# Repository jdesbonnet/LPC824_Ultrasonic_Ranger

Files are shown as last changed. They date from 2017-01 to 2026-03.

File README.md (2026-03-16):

# LPC824_Ultrasonic_Ranger

This is a sonar sensor comprising a LPC824 ARM Cortex M0+ MCU, low cost 40kHz ultrasonic transducers and opamps. The firmware
uses the LPC824 ADC DMA (direct memory access) capability to read analog samples at high speed into SRAM.

Unlike many ranging sensors that output just distance to target, this project is 
designed to capture the entire echo of an ultrasonic 'ping'. Potential uses include
measuring agricultural crop yield. 

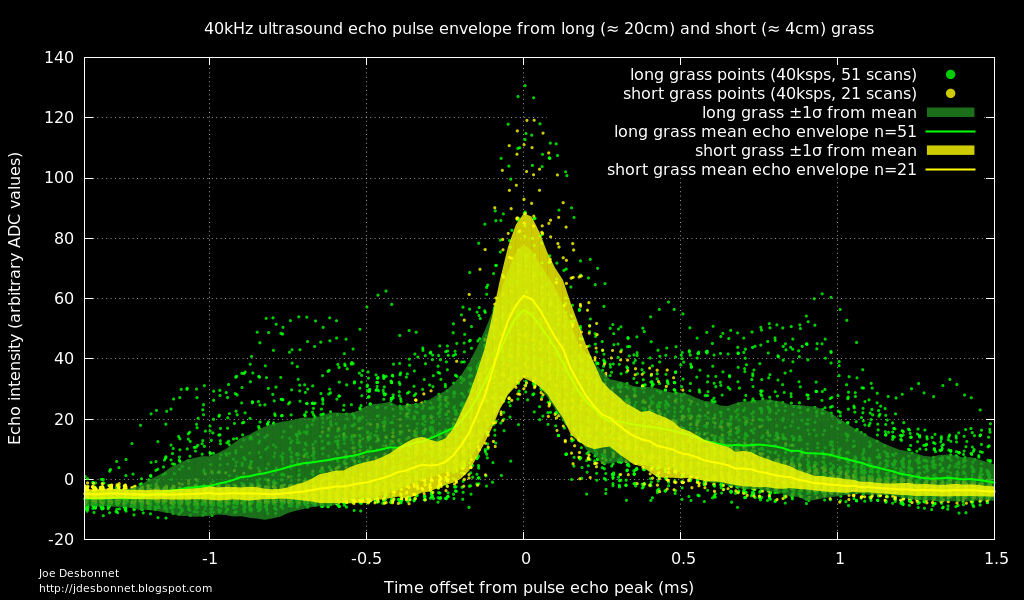
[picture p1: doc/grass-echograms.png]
echograms from long and short grass


## Frequency response of low cost 40kHz transducer

Method: a transmitter and transducer are taped together (separation distance 0).
An oscilloscope (Keysight DSO-X 3014A) waveform generator is set to 5V peak-to-peak 
sine wave, and the receiver is connected to a channel on oscilloscope set to 2V 
per division.  The frequency is varied around 40kHz using waveform generator menu. 
Only one device pair was tested. 

Observation: useful bandwidth is only 1kHz centered at about 40.5kHz. 

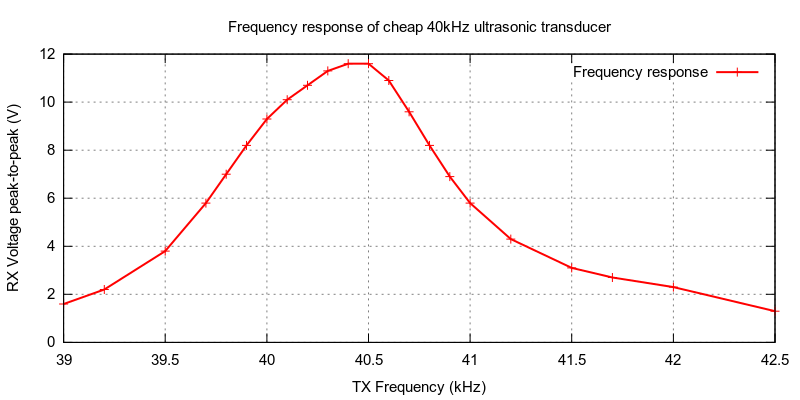
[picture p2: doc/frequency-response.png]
frequency response curve


Pulse (yellow) and echo (green) on oscilloscope:

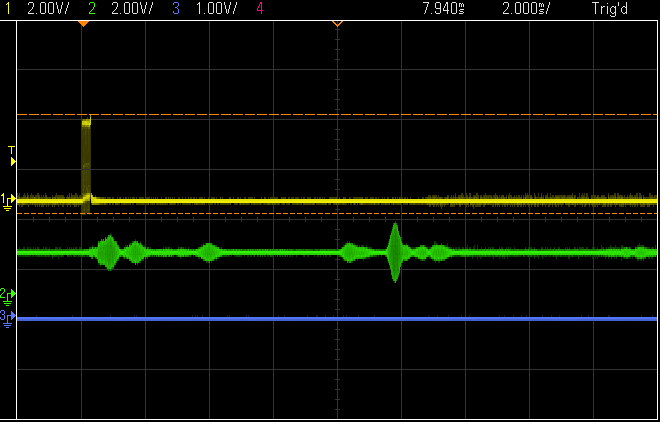
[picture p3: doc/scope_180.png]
echogram


## LPC824 pin utilization

|Pin| Function| |Pin | Function | |
|---| ---| ---|--- |---|---|
| 1 | ADC3 | RX amp out | 20 | PIO_0_14 | Debug pin |
| 2 | ADC9 | 2nd stage RX amp out | 19 | PIO0_0 | UART RXD |
| 3 | PIO0_13 | nc | 18 | VrefP | tied to 3.3V |
| 4 | PIO0_12 | nc | 17 | VrefN | tied to GND |
| 5 | RESET | SWD reset | 16 | Vss | |
| 6 | PIO0_4  | UART TXD | 15 | Vdd | |
| 7 | SWCLK | SWD clock | 14 | PIO0_8 | nc |
| 8 | SWDIO | SWD data | 13 | PIO0_9 | Transducer TX_B |
| 9 | PIO0_11 | nc | 12 | PIO0_1 | nc |
|10 | PIO0_10 | nc | 11 | PIO0_15  | Transducer TX_A |

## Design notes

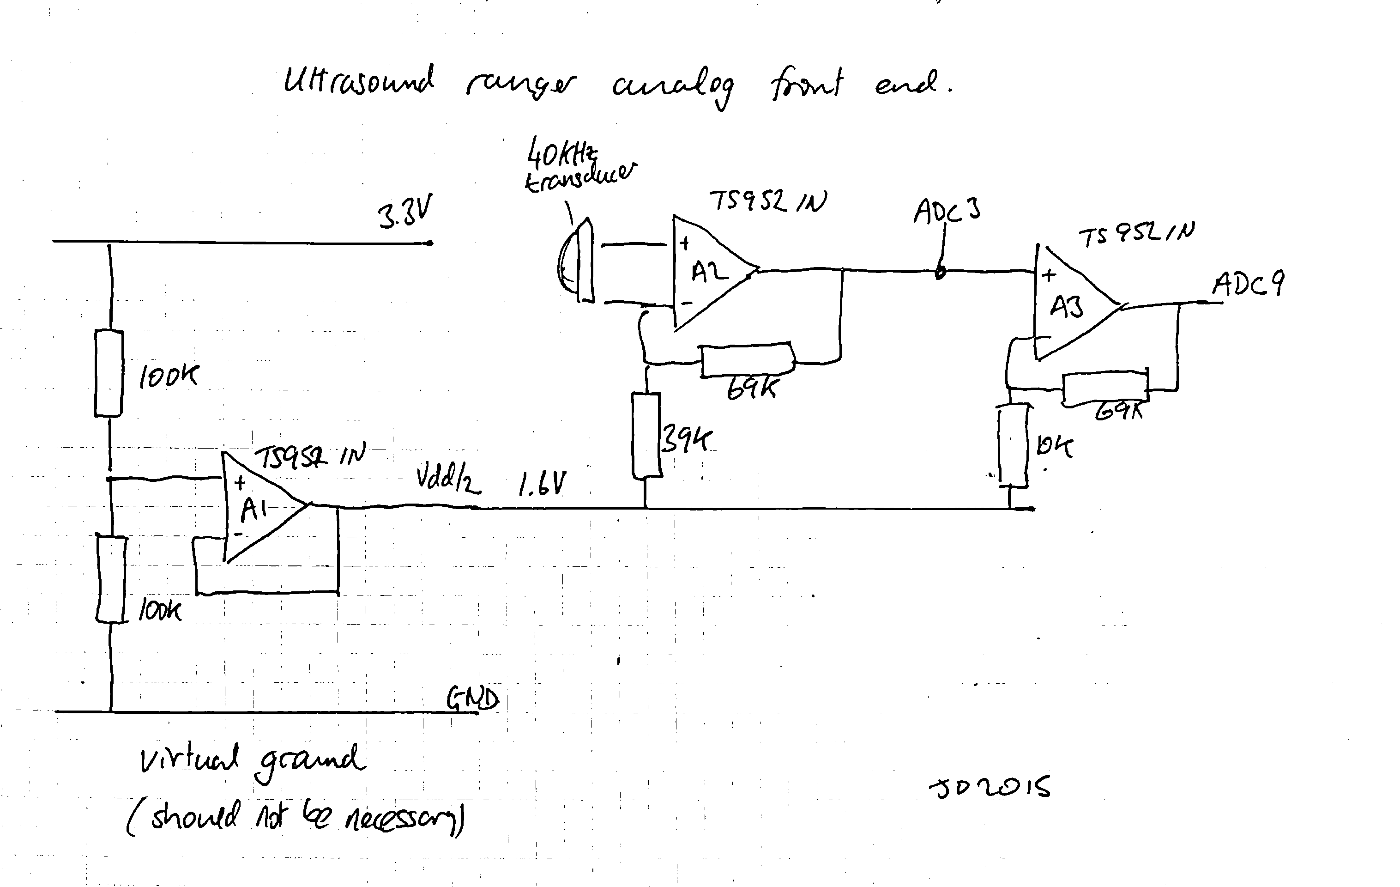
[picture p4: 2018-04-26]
doc/prototype-schematic.png

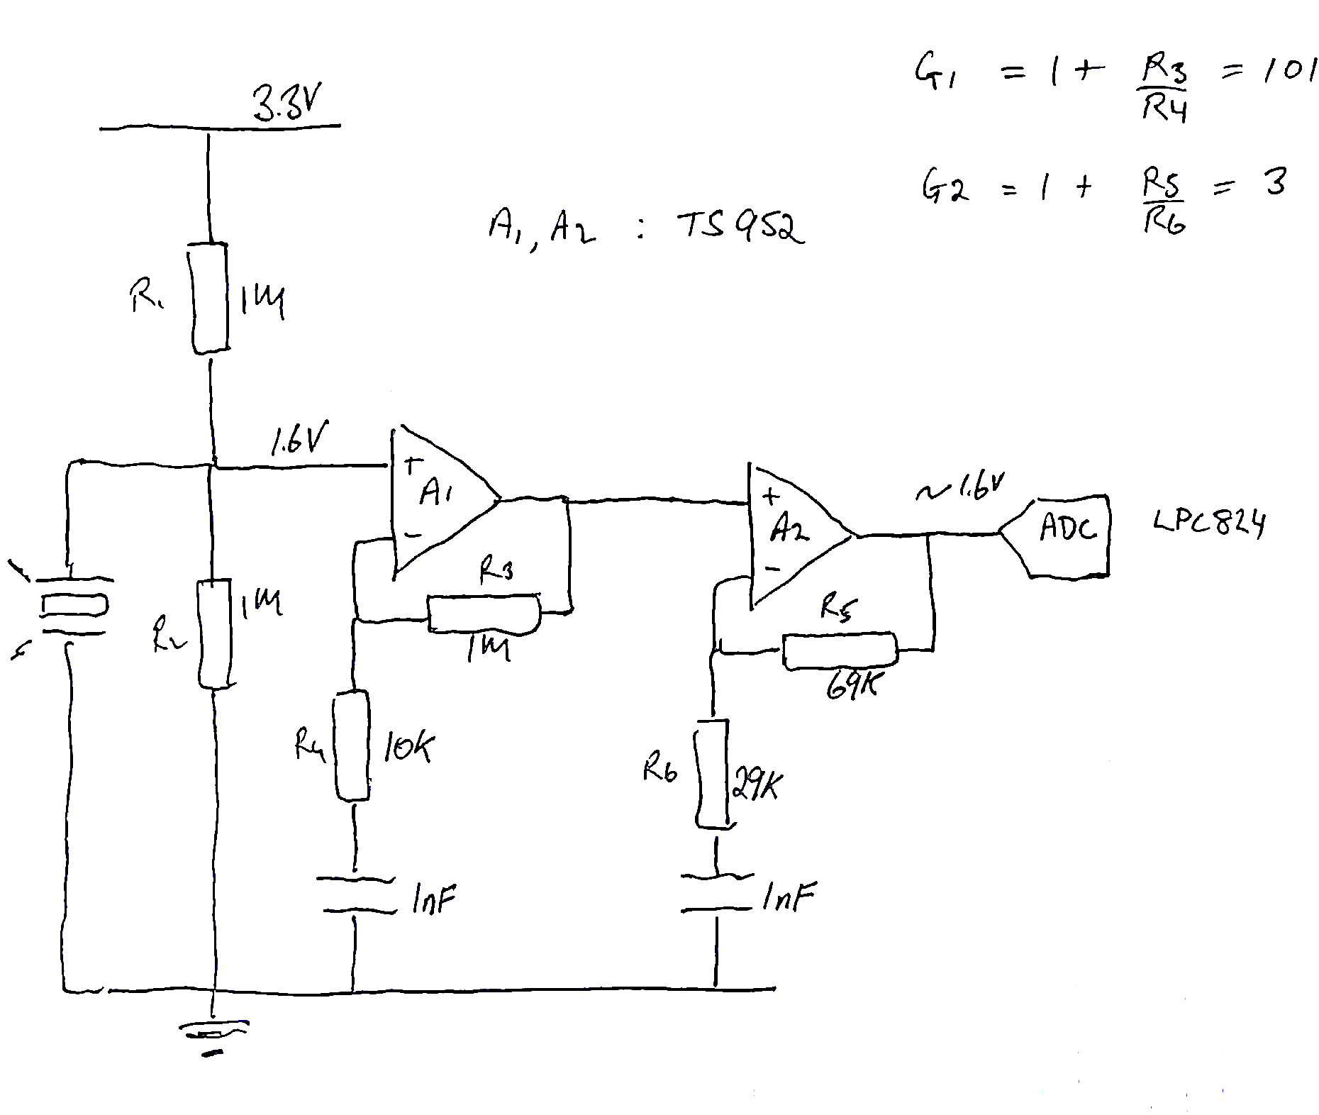
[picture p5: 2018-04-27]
doc/prototype-schematic2.png

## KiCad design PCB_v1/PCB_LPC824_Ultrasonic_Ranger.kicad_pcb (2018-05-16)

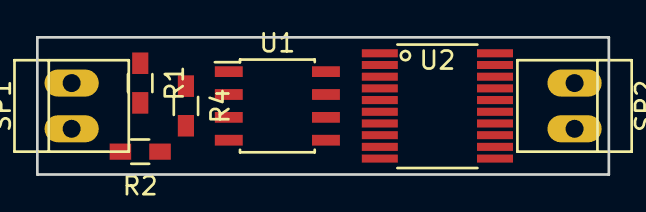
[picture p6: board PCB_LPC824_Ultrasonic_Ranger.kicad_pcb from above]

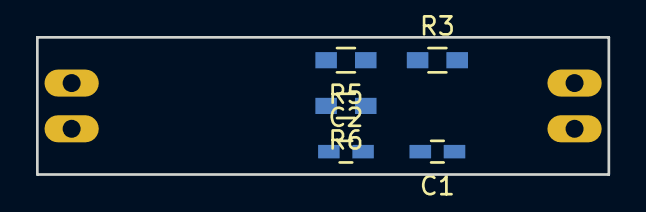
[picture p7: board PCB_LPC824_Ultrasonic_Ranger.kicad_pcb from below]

Board: 2 copper layers, 31.8 x 7.6 mm, 12 parts (5 on the bottom side), 11 nets, no tracks yet.

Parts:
C1, C2: C; C_0603_HandSoldering
R1, R2, R3, R4, R5, R6: R; R_0603_HandSoldering
SP1, SP2: SPEAKER; PINHEAD1-2
U1: OP275; SOIC-8_3.9x4.9mm_Pitch1.27mm
U2: LPC824M201JDH20; TSSOP-20_4.4x6.5mm_Pitch0.65mm

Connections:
+3V3: R1.1, U1.8, U2.15, U2.18
ADC3: R3.1, U1.1, U1.5, U2.1
ADC9: R5.1, U1.7, U2.2
GND: C1.2, C2.2, R2.2, SP1.1, U1.4, U2.16, U2.17
unnamed: C1.1, R4.2
unnamed: C2.1, R6.2
unnamed: R1.2, R2.1, SP1.2, U1.3
unnamed: R3.2, R4.1, U1.2
unnamed: R5.2, R6.1, U1.6
TX_A: SP2.2, U2.10
TX_B: SP2.1, U2.9

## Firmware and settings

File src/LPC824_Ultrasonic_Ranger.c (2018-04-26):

/*
===============================================================================
 Name        : LPC824_Ultrasonic_Ranger.c
 Author      : Joe Desbonnet, jdesbonnet@gmail.com
 Version     : 1.0 (16 July 2015)
 Copyright   : None.
 Description : Ultrasonic ranger application. Use SCT to send 40kHz pulse train
 to TX transducer. RX trandsucer amplified and connected to ADC. Use ADC to SRAM
 DMA to transfer ADC samples directly to memory.

 DMA transfers are limited to 1024 words (which can be 8,16 or 32 bit words). However
 transfers can be chained to facilitate longer data capture. This is illustrated in
 this example by chaining 3 DMA transfers of 1024 words (samples) back-to-back. ADC
 samples are triggered using the SCT (SCT0_OUT3 is programmed as the ADC sample trigger).
 Since the DMA supports transfers of 8, 16, 32 bit words, I am transferring the lower
 16 bits of the ADC data register. Note that bits 15:4 of the ADC data register hold
 the ADC value. So a shift right of 4 bits (>>4) needs to be performed on each
 16 bit word by the CPU after capture to yield ADC values 0 - 4095.

 This example is built upon examples provided by NXP for the LPC824. I recommend having
 chapters 21 (ADC), 11,12 (DMA), 16 (SCT) of UM10800 LPC82x User Manual for reference.

 There is a dependency on the lpc_chip_82x project/library which can be downloaded from:
 https://www.lpcware.com/content/nxpfile/lpcopen-software-development-platform-lpc8xx-packages

===============================================================================
*/

#if defined (__USE_LPCOPEN)
#if defined(NO_BOARD_LIB)
#include "chip.h"
#else
#include "board.h"
#endif
#endif

#include <cr_section_macros.h>

//
// Hardware configuration
//
//#define UART_BAUD_RATE 115200
#define UART_BAUD_RATE 230400

#define ADC_CHANNEL 3

// Sample period = 1024*3 / ADC_SAMPLE_RATE
// 500ksps: 6.1ms (1044mm)
// 800ksps: 3.84ms
// 1200ksps: 2.56ms (435mm)
// Max sample rate 1200ksps.
#define ADC_SAMPLE_RATE 500000

#define TRANSDUCER_FREQUENCY 40000
#define PULSE_CYCLE_COUNT 1

// Define function to pin mapping. Pin numbers here refer to PIO0_n
// and is not the same as a package pin number.
// Use PIO0_0 and PIO0_4 for UART RXD, TXD (same as ISP)
#define PIN_UART_RXD 0
#define PIN_UART_TXD 4
// General purpose debug pin
#define PIN_DEBUG 14

#define PIN_TRANSDUCER_TX_A 15
#define PIN_TRANSDUCER_TX_B 9

// Assign SCT0_OUT3 to external pin for debugging
#define PIN_SCT_DEBUG 15


#define DMA_BUFFER_SIZE 1024

static DMA_CHDESC_T dmaDescA;
static DMA_CHDESC_T dmaDescB;
static DMA_CHDESC_T dmaDescC;

// This is where we put ADC results
static uint16_t adc_buffer[DMA_BUFFER_SIZE*3];

static volatile int dmaBlockCount = 0;
static volatile int numPulseCycle = 0;


/**
 * @brief Pulse debugging pin to indicate an event on a oscilloscope trace.
 * @param n Number of times to pulse the pin.
 * @return None
 */
static void debug_pin_pulse (int n)
{
	int i;
	for (i = 0; i < n; i++) {
		Chip_GPIO_SetPinState(LPC_GPIO_PORT, 0, PIN_DEBUG, true);
		Chip_GPIO_SetPinState(LPC_GPIO_PORT, 0, PIN_DEBUG, false);
	}
}

/**
 * @brief Send one byte to UART. Block if UART busy.
 * @param n Byte to send to UART.
 * @return None.
 */
static void print_byte (uint8_t n) {
	//Chip_UART_SendBlocking(LPC_USART0, &n, 1);

	// Wait until data can be written to FIFO (TXRDY==1)
	while ( (Chip_UART_GetStatus(LPC_USART0) & UART_STAT_TXRDY) == 0) {}

	Chip_UART_SendByte(LPC_USART0, n);
}

/**
 * @brief Print a signed integer in decimal radix.
 * @param n Number to print.
 * @return None.
 */
static void print_decimal (int n) {
	char buf[10];
	int i = 0;

	// Special case of n==0
	if (n == 0) {
		print_byte('0');
		return;
	}

	// Handle negative numbers
	if (n < 0) {
		print_byte('-');
		n = -n;
	}

	// Use modulo 10 to get least significant digit.
	// Then /10 to shift digits right and get next least significant digit.
	while (n > 0) {
		buf[i++] = '0' + n%10;
		n /= 10;
	}

	// Output digits in reverse order
	do {
		print_byte (buf[--i]);
	} while (i>0);

}

/**
 * @brief	DMA Interrupt Handler
 * @return	None
 */
void DMA_IRQHandler(void)
{
	// Pulse debug pin so can see when each DMA block ends on scope trace.
	debug_pin_pulse (8);

	// Clear DMA interrupt for the channel
	Chip_DMA_ClearActiveIntAChannel(LPC_DMA, DMA_CH0);

	// Increment the DMA counter. When 3 the main loop knows we're done.
	dmaBlockCount++;
}

/**
 * @brief	Handle interrupt from State Configurable Timer
 * @return	Nothing
 */
void SCT_IRQHandler(void)
{

	numPulseCycle++;
	debug_pin_pulse(1);

	/* Clear the SCT Event 0 Interrupt */
	Chip_SCT_ClearEventFlag(LPC_SCT, SCT_EVT_0);
}

void setup_dma_for_adc (void) {
	// Setup DMA for ADC

	/* DMA initialization - enable DMA clocking and reset DMA if needed */
	Chip_DMA_Init(LPC_DMA);
	/* Enable DMA controller and use driver provided DMA table for current descriptors */
	Chip_DMA_Enable(LPC_DMA);
	Chip_DMA_SetSRAMBase(LPC_DMA, DMA_ADDR(Chip_DMA_Table));

	/* Setup channel 0 for the following configuration:
	   - High channel priority
	   - Interrupt A fires on descriptor completion */
	Chip_DMA_EnableChannel(LPC_DMA, DMA_CH0);
	Chip_DMA_EnableIntChannel(LPC_DMA, DMA_CH0);
	Chip_DMA_SetupChannelConfig(LPC_DMA, DMA_CH0,
			(DMA_CFG_HWTRIGEN
					//| DMA_CFG_PERIPHREQEN  //?? what's this for???
					| DMA_CFG_TRIGTYPE_EDGE
					| DMA_CFG_TRIGPOL_HIGH
					| DMA_CFG_TRIGBURST_BURST
					| DMA_CFG_BURSTPOWER_1
					 | DMA_CFG_CHPRIORITY(0)
					 ));

	// Attempt to use ADC SEQA to trigger DMA xfer
	Chip_DMATRIGMUX_SetInputTrig(LPC_DMATRIGMUX, DMA_CH0, DMATRIG_ADC_SEQA_IRQ);

	// DMA is performed in 3 separate chunks (as max allowed in one transfer
	// is 1024 words). First to go is dmaDescA followed by B and C.

	// DMA descriptor for ADC to memory - note that addresses must
	// be the END address for source and destination, not the starting address.
	// DMA operations moves from end to start. [Ref ].
	dmaDescC.xfercfg = 			 (
			DMA_XFERCFG_CFGVALID  // Channel descriptor is considered valid
			| DMA_XFERCFG_SETINTA // DMA Interrupt A (A vs B can be read in ISR)
			| DMA_XFERCFG_WIDTH_16 // 8,16,32 bits allowed
			| DMA_XFERCFG_SRCINC_0 // do not increment source
			| DMA_XFERCFG_DSTINC_1 // increment dst by widthx1
			| DMA_XFERCFG_XFERCOUNT(DMA_BUFFER_SIZE)
			);
	dmaDescC.source = DMA_ADDR ( (&LPC_ADC->DR[ADC_CHANNEL]) );
	dmaDescC.dest = DMA_ADDR(&adc_buffer[DMA_BUFFER_SIZE*3 - 1]) ;
	dmaDescC.next = DMA_ADDR(0); // no more descriptors

	dmaDescB.xfercfg = 			 (
			DMA_XFERCFG_CFGVALID  // Channel descriptor is considered valid
			| DMA_XFERCFG_RELOAD  // Causes DMA to move to next descriptor when complete
			| DMA_XFERCFG_SETINTA // DMA Interrupt A (A vs B can be read in ISR)
			//| DMA_XFERCFG_SWTRIG  // When written by software, the trigger for this channel is set immediately.
			| DMA_XFERCFG_WIDTH_16 // 8,16,32 bits allowed
			| DMA_XFERCFG_SRCINC_0 // do not increment source
			| DMA_XFERCFG_DSTINC_1 // increment dst by widthx1
			| DMA_XFERCFG_XFERCOUNT(DMA_BUFFER_SIZE)
			);
	dmaDescB.source = DMA_ADDR ( (&LPC_ADC->DR[ADC_CHANNEL]) );
	dmaDescB.dest = DMA_ADDR(&adc_buffer[DMA_BUFFER_SIZE*2 - 1]) ;
	dmaDescB.next = (uint32_t)&dmaDescC;

	// ADC data register is source of DMA
	dmaDescA.source = DMA_ADDR ( (&LPC_ADC->DR[ADC_CHANNEL]) );
	dmaDescA.dest = DMA_ADDR(&adc_buffer[DMA_BUFFER_SIZE - 1]) ;
	dmaDescA.next = (uint32_t)&dmaDescB;



	// Enable DMA interrupt. Will be invoked at end of DMA transfer.
	NVIC_EnableIRQ(DMA_IRQn);

	/* Setup transfer descriptor and validate it */
	Chip_DMA_SetupTranChannel(LPC_DMA, DMA_CH0, &dmaDescA);
	Chip_DMA_SetValidChannel(LPC_DMA, DMA_CH0);

	// Setup data transfer and hardware trigger
	// See "Transfer Configuration registers" UM10800, §12.6.18, Table 173, page 179
	Chip_DMA_SetupChannelTransfer(LPC_DMA, DMA_CH0,
			 (
				DMA_XFERCFG_CFGVALID  // Channel descriptor is considered valid
				| DMA_XFERCFG_RELOAD  // Causes DMA to move to next descriptor when complete
				| DMA_XFERCFG_SETINTA // DMA Interrupt A (A vs B can be read in ISR)
				//| DMA_XFERCFG_SWTRIG  // When written by software, the trigger for this channel is set immediately.
				| DMA_XFERCFG_WIDTH_16 // 8,16,32 bits allowed
				| DMA_XFERCFG_SRCINC_0 // do not increment source
				| DMA_XFERCFG_DSTINC_1 // increment dst by widthx1
				| DMA_XFERCFG_XFERCOUNT(DMA_BUFFER_SIZE)
				)
				);
}

void setup_sct_for_transducer (void) {

	//
	// Setup SCT to produce a driving signal for 40kHz transducer. Require
	// 40kHz square wave with 50% duty cycle. But require output on two pins
	// in anti-phase with each other. Ie pin A and B where A == !B. Event0
	// occurs at the end of the cycle, Event2 in the middle of the cycle.
	//

	Chip_SCT_Init(LPC_SCT);

	/* Stop the SCT before configuration */
	Chip_SCTPWM_Stop(LPC_SCT);

	// Match/capture mode register. (ref UM10800 section 16.6.11, Table 232, page 273)
	// Determines if match/capture operate as match or capture. Want all match.
	LPC_SCT->REGMODE_U = 0;


	// Event 0 control: (ref UM10800 section 16.6.25, Table 247, page 282).
	// set MATCHSEL (bits 3:0) = MATCH0 register(0)
	// set COMBMODE (bits 13:12)= MATCH only(1)
	// So Event0 is triggered on match of MATCH0
	LPC_SCT->EV[0].CTRL =   (0 << 0 )
							| 1 << 12;
	// Event enable register (ref UM10800 section 16.6.24, Table 246, page 281)
	// Enable Event0 in State0 (default state). We are not using states,
	// so this enables Event0 in the default State0.
	// Set STATEMSK0=1
	LPC_SCT->EV[0].STATE = 1<<0;


	// Configure Event2 to be triggered on Match2. This occurs mid-cycle.
	LPC_SCT->EV[2].CTRL =
						(2 << 0) // The match register (MATCH2) associated with this event
						| (1 << 12); // COMBMODE=1 (MATCH only)
	LPC_SCT->EV[2].STATE = 1; // Enable Event2 in State0 (default state)


	// Clear the output in-case of conflict.
	// Ref UM10800 section 16.6.14 SCT conflict resolution regiser
	// TODO: explain
	// int pin=0
	//LPC_SCT->RES = (LPC_SCT->RES & ~(3 << (pin << 1))) | (0x01 << (pin << 1));
	LPC_SCT->RES = (1<<0);

	/* Set and Clear do not depend on direction */
	//LPC_SCT->OUTPUTDIRCTRL = (LPC_SCT->OUTPUTDIRCTRL & ~((3 << (pin << 1))|SCT_OUTPUTDIRCTRL_RESERVED));


	// Set SCT Counter to count 32-bits and reset to 0 after reaching MATCH0
	Chip_SCT_Config(LPC_SCT, SCT_CONFIG_32BIT_COUNTER | SCT_CONFIG_AUTOLIMIT_L);

	// Setup SCT for ADC/DMA sample timing.
	uint32_t clock_hz =  Chip_Clock_GetSystemClockRate();
	Chip_SCT_SetMatchReload(LPC_SCT, SCT_MATCH_2, (clock_hz/TRANSDUCER_FREQUENCY)/2 );
	Chip_SCT_SetMatchReload(LPC_SCT, SCT_MATCH_0,  clock_hz/TRANSDUCER_FREQUENCY);

	// Using SCT0_OUT3 to trigger ADC sampling
	// Set SCT0_OUT3 on Event0 (Event0 configured to occur on Match0)
	LPC_SCT->OUT[0].SET = 1 << 0;
	LPC_SCT->OUT[1].CLR = 1 << 0;

	// Clear SCT0_OUT3 on Event2 (Event2 configured to occur on Match2)
	LPC_SCT->OUT[0].CLR = 1 << 2;
	LPC_SCT->OUT[1].SET = 1 << 2;

	// SwitchMatrix: Assign SCT_OUT3 to external pin for debugging
	Chip_Clock_EnablePeriphClock(SYSCTL_CLOCK_SWM);
	Chip_SWM_MovablePinAssign(SWM_SCT_OUT0_O, PIN_TRANSDUCER_TX_A);
	Chip_SWM_MovablePinAssign(SWM_SCT_OUT1_O, PIN_TRANSDUCER_TX_B);
	Chip_Clock_DisablePeriphClock(SYSCTL_CLOCK_SWM);

	// Enable IRQ at the end of each cycle (Event0) so that a different period
	// can be loaded into the match registers.
	Chip_SCT_EnableEventInt(LPC_SCT, SCT_EVT_2);
	NVIC_EnableIRQ(SCT_IRQn);

}

void setup_sct_for_adc (void) {

	//
	// Setup SCT to trigger ADC sampling. Configure a square wave with sampling frequency, 50% duty cycle.
	//

	Chip_SCT_Init(LPC_SCT);

	/* Stop the SCT before configuration */
	Chip_SCTPWM_Stop(LPC_SCT);

	// Match/capture mode register. (ref UM10800 section 16.6.11, Table 232, page 273)
	// Determines if match/capture operate as match or capture. Want all match.
	LPC_SCT->REGMODE_U = 0;


	// Event 0 control: (ref UM10800 section 16.6.25, Table 247, page 282).
	// set MATCHSEL (bits 3:0) = MATCH0 register(0)
	// set COMBMODE (bits 13:12)= MATCH only(1)
	// So Event0 is triggered on match of MATCH0
	LPC_SCT->EV[0].CTRL =   (0 << 0 )
							| 1 << 12;
	// Event enable register (ref UM10800 section 16.6.24, Table 246, page 281)
	// Enable Event0 in State0 (default state). We are not using states,
	// so this enables Event0 in the default State0.
	// Set STATEMSK0=1
	LPC_SCT->EV[0].STATE = 1<<0;


	// Configure Event2 to be triggered on Match2
	LPC_SCT->EV[2].CTRL =
						(2 << 0) // The match register (MATCH2) associated with this event
						| (1 << 12); // COMBMODE=1 (MATCH only)
	LPC_SCT->EV[2].STATE = 1; // Enable Event2 in State0 (default state)


	/* Clear the output in-case of conflict */
	int pin = 0;
	LPC_SCT->RES = (LPC_SCT->RES & ~(3 << (pin << 1))) | (0x01 << (pin << 1));

	/* Set and Clear do not depend on direction */
	LPC_SCT->OUTPUTDIRCTRL = (LPC_SCT->OUTPUTDIRCTRL & ~((3 << (pin << 1))|SCT_OUTPUTDIRCTRL_RESERVED));


	// Set SCT Counter to count 32-bits and reset to 0 after reaching MATCH0
	Chip_SCT_Config(LPC_SCT, SCT_CONFIG_32BIT_COUNTER | SCT_CONFIG_AUTOLIMIT_L);

	// Setup SCT for ADC/DMA sample timing.
	uint32_t clock_hz =  Chip_Clock_GetSystemClockRate();
	Chip_SCT_SetMatchReload(LPC_SCT, SCT_MATCH_2, (clock_hz/ADC_SAMPLE_RATE)/2 );
	Chip_SCT_SetMatchReload(LPC_SCT, SCT_MATCH_0,  clock_hz/ADC_SAMPLE_RATE);

	// Using SCT0_OUT3 to trigger ADC sampling
	// Set SCT0_OUT3 on Event0 (Event0 configured to occur on Match0)
	LPC_SCT->OUT[3].SET = 1 << 0;
	// Clear SCT0_OUT3 on Event2 (Event2 configured to occur on Match2)
	LPC_SCT->OUT[3].CLR = 1 << 2;

	// SwitchMatrix: Assign SCT_OUT3 to external pin for debugging
	//Chip_Clock_EnablePeriphClock(SYSCTL_CLOCK_SWM);
	//Chip_SWM_MovablePinAssign(SWM_SCT_OUT3_O, PIN_SCT_DEBUG);
	//Chip_Clock_DisablePeriphClock(SYSCTL_CLOCK_SWM);

}

int main(void) {

	int i;

	//
	// Enable clock to MCU subsystems needed in this application. Need IOCON
	// to disable pullup on ADC input.
	//
    LPC_SYSCON->SYSAHBCLKCTRL |=
    		(1<<18) // IOCON
			;


	//
	// Initialize GPIO
	//
	Chip_GPIO_Init(LPC_GPIO_PORT);
	Chip_GPIO_SetPinDIROutput(LPC_GPIO_PORT, 0, PIN_DEBUG);

	Chip_GPIO_SetPinDIROutput(LPC_GPIO_PORT, 0, PIN_TRANSDUCER_TX_A);
	Chip_GPIO_SetPinDIROutput(LPC_GPIO_PORT, 0, PIN_TRANSDUCER_TX_B);



	Chip_GPIO_SetPinState(LPC_GPIO_PORT, 0, 15, false);

	//
	// Initialize UART
	//

	// Assign pins: use same assignment as serial bootloader
	Chip_Clock_EnablePeriphClock(SYSCTL_CLOCK_SWM);
	Chip_SWM_MovablePinAssign(SWM_U0_TXD_O, PIN_UART_TXD);
	Chip_SWM_MovablePinAssign(SWM_U0_RXD_I, PIN_UART_RXD);
	Chip_Clock_DisablePeriphClock(SYSCTL_CLOCK_SWM);

	Chip_UART_Init(LPC_USART0);
	Chip_UART_ConfigData(LPC_USART0,
			UART_CFG_DATALEN_8
			| UART_CFG_PARITY_NONE
			| UART_CFG_STOPLEN_1);

	Chip_Clock_SetUSARTNBaseClockRate((UART_BAUD_RATE * 16), true);
	Chip_UART_SetBaud(LPC_USART0, UART_BAUD_RATE);
	Chip_UART_TXEnable(LPC_USART0);
	Chip_UART_Enable(LPC_USART0);



	//
	// Setup ADC
	//

	// Disable pullup/pull down on ADC pin: this solves the mysterious
	// pulling up of the ADC pin to almost Vdd. PIO0_23 = ADC3 = TSSOP package pin 1.
	Chip_IOCON_PinSetMode(LPC_IOCON, IOCON_PIO23, PIN_MODE_INACTIVE);

	Chip_ADC_Init(LPC_ADC, 0);

	// Need to do a calibration after initialization
	Chip_ADC_StartCalibration(LPC_ADC);
	while (!(Chip_ADC_IsCalibrationDone(LPC_ADC))) {}

	// Sampling clock rate (not conversion rate). A fully accurate conversion
	// requires 25 ADC clock cycles.
	//Chip_ADC_SetClockRate(LPC_ADC, 500000 * 25);
	Chip_ADC_SetClockRate(LPC_ADC, ADC_MAX_SAMPLE_RATE);
	Chip_ADC_SetDivider(LPC_ADC,0);

	// Setup a sequencer A to do the following: (ref UM10800, 21.6.2, Table (undefined).)
	// * Do conversions on channel ADC_CHANNEL only
	// * Trigger sampling on SCT0_OUT3  See UM10800 §21.3.3, Table 276.
	// Note, as far as I can tell, ADC_SEQ_CTRL_HWTRIG_* defines are incorrect for LPC824.
	// * Mode END_OF_SEQ : trigger DMA/interrupt when sequence is complete.
	Chip_ADC_SetupSequencer(LPC_ADC,
							ADC_SEQA_IDX,
							(ADC_SEQ_CTRL_CHANSEL(ADC_CHANNEL)
							//| ADC_SEQ_CTRL_HWTRIG_SCT_OUT1
							| (3<<12) // trig on SCT0_OUT3.
							| ADC_SEQ_CTRL_MODE_EOS
							)
									);

	// Enable fixed pin ADC3, ADC9 with SwitchMatrix. Cannot move ADC pins.
	Chip_Clock_EnablePeriphClock(SYSCTL_CLOCK_SWM);
	Chip_SWM_EnableFixedPin(SWM_FIXED_ADC3);
	Chip_Clock_DisablePeriphClock(SYSCTL_CLOCK_SWM);

	/* Clear all pending interrupts */
	Chip_ADC_ClearFlags(LPC_ADC, Chip_ADC_GetFlags(LPC_ADC));


	// This has impact on DMA operation. Why?
	Chip_ADC_EnableInt(LPC_ADC, (ADC_INTEN_SEQA_ENABLE
								//| ADC_INTEN_OVRRUN_ENABLE
								));


	/* Enable sequencer */
	Chip_ADC_EnableSequencer(LPC_ADC, ADC_SEQA_IDX);




	//
	// Main loop
	//
	while (1) {

		// Setup SCT for driving transducer and start SCT
		setup_sct_for_transducer();
		numPulseCycle = 0;
		debug_pin_pulse(2);
		Chip_SCT_ClearControl(LPC_SCT, SCT_CTRL_HALT_L | SCT_CTRL_HALT_H);
		while (numPulseCycle < PULSE_CYCLE_COUNT) {
			__WFI();
		}
		Chip_SCT_SetControl(LPC_SCT, SCT_CTRL_HALT_L | SCT_CTRL_HALT_H);


		setup_dma_for_adc();

		setup_sct_for_adc();


		// Start SCT
		Chip_SCT_ClearControl(LPC_SCT, SCT_CTRL_HALT_L | SCT_CTRL_HALT_H);

		// Loop until dmaBlockCount==3 (this is updated in the DMA interrupt service routine)
		dmaBlockCount = 0;
		while (dmaBlockCount < 3) {
			// Save power by sleeping as much as possible while waiting for DMAs to complete.
			__WFI();
		}


		// Done with ADC sampling, stop and switch off SCT, ADC
		//Chip_SCT_DeInit(LPC_SCT);
		//Chip_ADC_DeInit(LPC_ADC);
		//NVIC_DisableIRQ(DMA_IRQn);

		// DMA complete. Now shift ADC data register values 4 bits right to yield
		// 12 bit ADC data in range 0 - 4095
		for (i = 0; i < DMA_BUFFER_SIZE * 3; i++) {
			adc_buffer[i] >>= 4;
		}

		// Output ADC values to UART.
		// Format: record-number adc-value.
		// One record per line.  Suggest using GnuPlot to plot them.

		// Record header
		print_byte('W');
		print_byte(' ');
		for (i = 0; i < DMA_BUFFER_SIZE * 3; i++) {
			// It would be nice to use libc, but complicates packing up for others to use.
			//printf ("%d %d\n", i, adc_buffer[i]);
			// Use simple UART printing functions embedded in C file instead of libc.
			//print_decimal(i);
			//print_byte(' ');
			//print_decimal(adc_buffer[i]);

			// Base64 encoded for faster throughput. First byte upper (most
			// significant) 6 bits of ADC reading, second byte lower 6 bits.
			print_byte(((adc_buffer[i]>>6)&0x3f) + '?');
			print_byte((adc_buffer[i]&0x3f) + '?');
		}
		print_byte('\r');
		print_byte('\n');

	}

}

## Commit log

2017-01-22 start with ADC DMA example
2017-01-23 pulse 40kHz transducer, output ADC and repeat
2017-01-25 add scope trace
2017-01-25 crop scope trace
2017-02-04 pin assignments
2017-02-04 update pin assignments
2018-04-26 diable internal pullup on ADC input
2018-04-26 schematic of prototype analog amp
2018-05-16 start PCB
    [PCB_LPC824_Ultrasonic_Ranger.kicad_pcb, PCB_LPC824_Ultrasonic_Ranger.sch]
2026-03-16 Update UART pin description in README
2026-03-16 Fix LPC824 pin utilization table formatting
